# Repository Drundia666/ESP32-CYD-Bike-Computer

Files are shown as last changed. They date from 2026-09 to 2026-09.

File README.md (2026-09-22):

# ESP32-CYD-Bike-Computer
Open-source ESP32-CYD-based (Cheap Yellow Display) bicycle computer with a graphical display, speed tracking, trip statistics, environmental sensors, and customizable UI

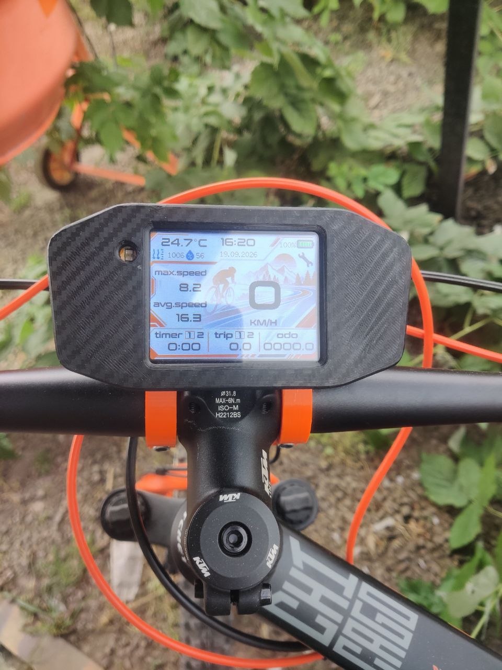
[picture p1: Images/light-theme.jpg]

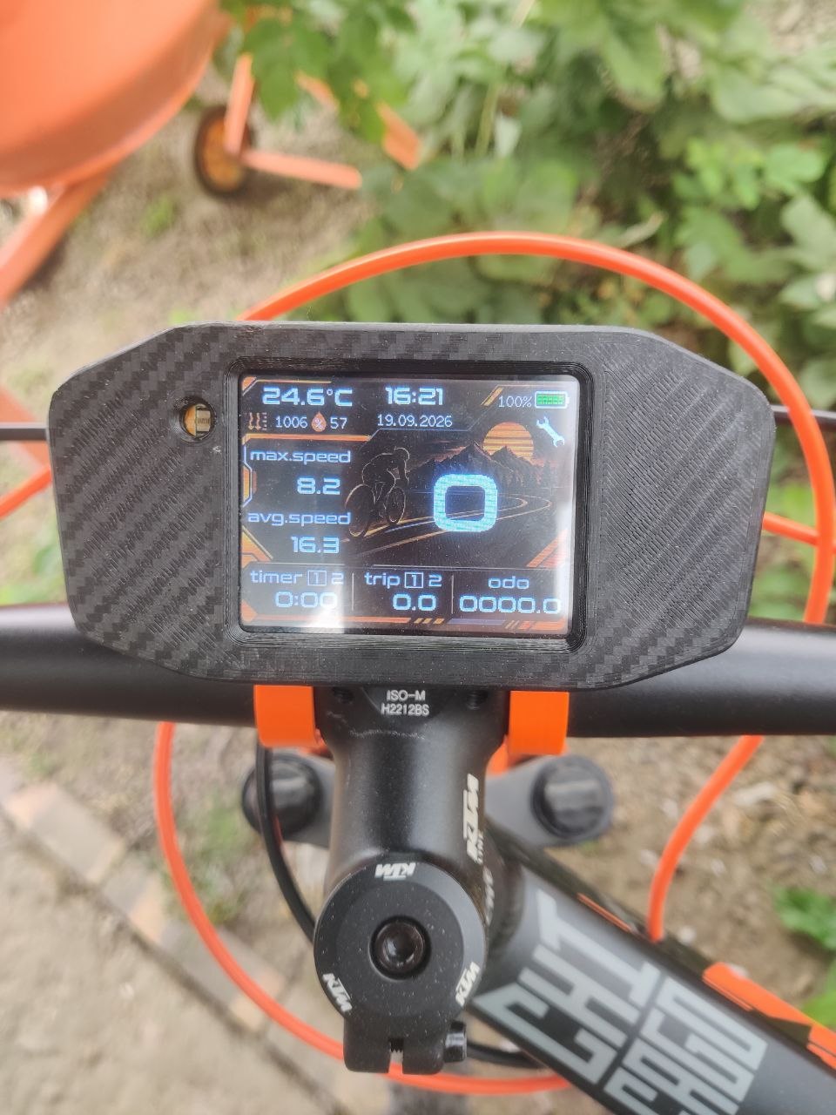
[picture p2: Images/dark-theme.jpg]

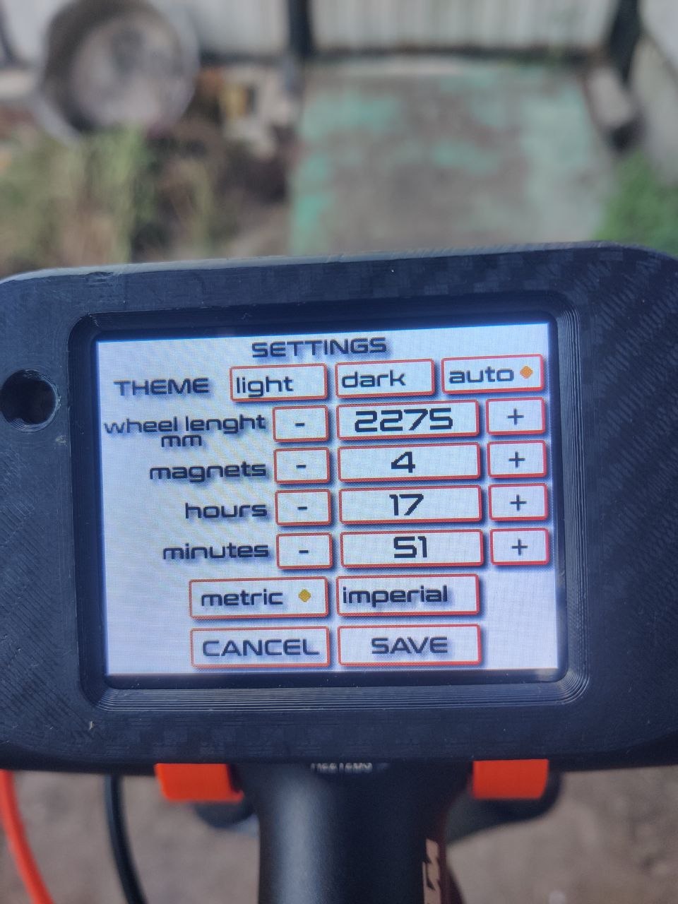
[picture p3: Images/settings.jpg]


## Features

- Real-time speed measurement
- Average and maximum speed
- Trip distance and total odometer
- Temperature, atmospheric pressure and humidity monitoring
- Trip timer

- Important Notice

This bike computer is a DIY hobby project intended for recreational use only.

It is not a professional-grade device.
Do not use it in competitions or situations where accurate measurements are critical.
It is not waterproof. Using it in rainy conditions is not recommended.

- # About the Project (для описания на русском листайте ниже)

The entire codebase was written by AI. It went through many iterations before I achieved the desired result, so the code may not be fully optimized.
This bike computer is installed on my personal KTM bicycle. That's also where the enclosure design comes from — it is inspired by the instrument cluster of the KTM Duke 790–890 motorcycles.
The mounting system should also fit bicycles from other brands with the following dimensions:

* Fork tube diameter: 35 mm
* Handlebar diameter at the mounting point: 32 mm
For other dimensions, you may need to make minor modifications to the 3D models of the mounting brackets.

---

## Assembly
Assembly is straightforward, but it requires basic soldering skills and some understanding of electrical circuits.

**The most important rule: always connect positive (+) to positive (+) and negative (−) to negative (−).**

If you don't understand the difference between positive and negative polarity, ask someone with electrical experience for help.

An assembly diagram is available in the `assembly photos` folder.

**Disclaimer:** I am not responsible for any damage caused by incorrect wiring or reversed polarity, including damage to microchips or other electronic components.

---

## Basic Operation

Using the bike computer is simple — turn it on and ride!

To turn it off, press and hold the button for 10 seconds.

### Timer

* Tap the **Timer** area to switch between active timers.
* Long-press the Timer area to reset the currently selected timer.

### Trip

* Tap the **Trip** area to switch between Trip 1 and Trip 2.
* Long-press the Trip area to reset the selected trip. This also resets the maximum and average speed recorded for that trip.

The total odometer runs continuously and saves its value to non-volatile memory every 100 meters.

### Battery Indicator

Tap the battery level indicator to switch between percentage (%) and voltage (V).

---

## Settings

Tap the wrench icon to open the Settings page.

### 1. Display Theme

Choose between three display modes:

* Light theme
* Dark theme
* Automatic switching based on the ambient light sensor

### 2. Wheel Circumference

The default wheel circumference is **2275 mm**, with an adjustment step of **5 mm**.

Alternatively, you can set the exact value directly in the source code.

Find the following line:

```cpp
float wheelCircumferenceMm = 2275;
```

Replace `2275` with your measured wheel circumference in millimeters.

### 3. Number of Wheel Magnets

Set the number of magnets installed on the wheel.

Using more magnets provides smoother speed measurements.

**Important:** If you use more than one magnet, they must be evenly spaced around the wheel, with an equal number of spokes between them.

### 4. Set Hours

Adjust the current hour.

### 5. Set Minutes

Adjust the current minute.

**Important:** The date is set automatically when the firmware is compiled. Therefore, the firmware must be compiled and uploaded on the same day to ensure the correct date.

### 6. Measurement Units

Choose between two measurement systems:

| Metric | Imperial |
| --- | --- |
| km | mi |
| km/h | mph |
| °C | °F |
| mmHg | inHg |

---

## How to Accurately Measure Wheel Circumference

Accurate wheel circumference measurement is important for correct speed and distance calculations.

Follow these steps:

1. Place your bicycle on a flat surface and position the wheel so that the tire valve is at the bottom, closest to the ground.
2. Make a mark on the ground directly below the valve.
3. Roll the bicycle forward until the wheel completes exactly one full revolution and the valve returns to the bottom.
4. Make a second mark on the ground.
5. Use a measuring tape to measure the distance between the two marks.

The measured distance is your wheel circumference in millimeters.

Enter this value in the bike computer settings or directly in the source code.

Troubleshooting
Speed Always Shows 0

If the speed reading remains at 0 km/h while riding, check the following:

Magnet is too far from the Hall sensor. The distance between the magnet and the sensor may be too large for reliable detection.
Magnet is not properly aligned. The magnet may be passing above or below the Hall sensor instead of directly in front of it.

Incorrect magnet polarity or Hall sensor orientation. The magnet may be facing the sensor with the wrong magnetic pole, or the Hall sensor may be installed facing the wrong direction.

Refer to the photos in the assembly photos folder for the correct Hall sensor orientation.

**Securing Components**

The magnetic USB connector, BME280 sensor, and 3-pin connector can be secured in place using a couple of drops of superglue.

It is recommended to secure the battery using hot glue. Additionally, place a thin layer of soft, electrically insulating material between the battery and the rear cover to provide cushioning and prevent direct contact.

## 🧡 Support the project

If you enjoy this project, you can support its development on Ko-fi.



# 🚴 Велокомпьютер на ESP32

Самодельный велокомпьютер на базе ESP32 с сенсорным управлением, измерением скорости и расстояния, двумя независимыми поездками, таймерами и возможностью настройки интерфейса.

Проект создан для личного использования и любительских экспериментов.

---

## ⚠️ Важная информация

> **Внимание!**
>
> * Устройство не является профессиональным измерительным прибором.
> * Не используйте его в соревнованиях.
> * Проект создан исключительно для любительского использования и развлечения.
> * Устройство не является водонепроницаемым. Использование во время дождя не рекомендуется.

---

## 📖 О проекте

Весь программный код написан с помощью ИИ (большая часть ChatGPT, также использован Claude и Github Copilot).

Проект прошёл множество итераций и доработок, прежде чем мне удалось получить желаемый результат. Поэтому код может быть не самым оптимальным, но он реализует необходимую мне функциональность.

Велокомпьютер установлен на моём личном велосипеде **KTM**. Именно поэтому корпус устройства стилизован под приборную панель мотоциклов KTM Duke 790–890.

### 🔧 Совместимость крепления

Крепление разработано под следующие размеры:

| Параметр | Размер |
| --- | --- |
| Диаметр пера вилки | 35 мм  |
| Диаметр руля в месте крепления | 32 мм  |

Устройство может подойти и для велосипедов других производителей с аналогичными размерами.

Если размеры вашего велосипеда отличаются, возможно, потребуется немного доработать 3D-модели крепёжных элементов.

---

## 🛠️ Сборка

Сборка достаточно простая, однако потребуются базовые навыки пайки и понимание основ электротехники.

### ⚡ Важно соблюдать полярность!

**Главное правило:**

* Плюс (+) соединяется с плюсом (+).
* Минус (−) соединяется с минусом (−).

Если вы не понимаете разницу между плюсом и минусом, обратитесь за помощью к человеку, имеющему опыт работы с электроникой.

📁 Схема сборки и фотографии правильного расположения компонентов находятся в папке `assembly photos`.

> ⚠️ **Отказ от ответственности**
>
> Автор не несёт ответственности за повреждение микросхем, датчиков и других электронных компонентов вследствие неправильного подключения, перепутанной полярности или ошибок при сборке.

---

## 🎮 Управление велокомпьютером

Управление максимально простое: включили устройство — и можно ехать!

### 🔘 Включение и выключение

| Действие | Результат |
| --- | --- |
| Включение устройства | Включите велокомпьютер и начинайте поездку |
| Удержание кнопки 10 секунд | Выключение устройства |

### ⏱️ Таймер — TIMER

Управление осуществляется касанием области `TIMER` на экране.

| Действие | Результат |
| --- | --- |
| Короткое касание | Переключение активного таймера |
| Долгое касание | Обнуление выбранного таймера |

### 🚴 Поездки — TRIP

Велокомпьютер поддерживает два независимых счётчика поездок: `TRIP 1` и `TRIP 2`.

| Действие | Результат |
| --- | --- |
| Короткое касание | Переключение между поездками 1 и 2 |
| Долгое касание | Сброс выбранной поездки |

При сбросе поездки также обнуляются:

* Максимальная скорость данной поездки.
* Средняя скорость данной поездки.

### 🛣️ Общий пробег — ODO

Общий одометр работает постоянно, независимо от выбранной поездки.

**Каждые 100 метров** значение общего пробега сохраняется в энергонезависимую память.

Это позволяет сохранять накопленный пробег после выключения устройства.

### 🔋 Индикатор батареи

Касание области индикатора заряда батареи переключает формат отображения:

* `%` — уровень заряда в процентах.
* `V` — напряжение аккумулятора в вольтах.

---

## ⚙️ Настройки

Чтобы открыть страницу настроек, коснитесь значка гаечного ключа 🔧 на экране.

В меню доступны следующие параметры.

### 1. 🎨 Тема оформления

Доступны три режима:

| Режим | Описание |
| --- | --- |
| Светлая тема | Светлое оформление интерфейса |
| Тёмная тема | Тёмное оформление интерфейса |
| Автоматический | Переключение темы по показаниям датчика освещённости |

### 2. 📏 Длина окружности колеса

Этот параметр необходим для правильного расчёта скорости и пройденного расстояния.

| Параметр | Значение |
| --- | --- |
| Значение по умолчанию | 2275 мм  |
| Шаг изменения | 5 мм |

Длину окружности можно изменить непосредственно в настройках велокомпьютера.

Также можно заранее указать необходимое значение в исходном коде.

Найдите строку:

```cpp
float wheelCircumferenceMm = 2275;
```

Замените `2275` на измеренную длину окружности вашего колеса в миллиметрах.

Подробная инструкция по измерению приведена ниже.

### 3. 🧲 Количество магнитов

Укажите количество магнитов, установленных на колесе.

Чем больше магнитов используется, тем плавнее происходит измерение скорости.

> ⚠️ **Важное правило**
>
> Если установлено более одного магнита, они должны располагаться равномерно по окружности колеса — через одинаковое количество спиц.

### 4. 🕒 Установка часов

Позволяет установить текущее значение часов.

### 5. 🕒 Установка минут

Позволяет установить текущее значение минут.

**Особенность установки даты:**

Дата устанавливается автоматически в момент компиляции прошивки.

Поэтому компиляция и загрузка прошивки в ESP32 должны выполняться в один и тот же день, чтобы дата была правильной.

### 6. 🌍 Система единиц измерения

Велокомпьютер поддерживает две системы единиц измерения.

| Параметр | Метрическая | Имперская |
| --- | :---: | :---: |
| Расстояние  | km | mi |
| Скорость | km/h | mph |
| Температура | °C | °F |
| Давление | mmHg | inHg |

---

## 📐 Как правильно измерить длину окружности колеса

Для точного измерения скорости и расстояния необходимо правильно указать длину окружности колеса.

Самый простой способ — измерить расстояние, которое велосипед проходит за один полный оборот колеса.

### Пошаговая инструкция

**Шаг 1. Подготовка**

Поставьте велосипед на ровную поверхность.

Поверните колесо так, чтобы ниппель находился в самой нижней точке, рядом с землёй.

**Шаг 2. Первая отметка**

Сделайте отметку на земле непосредственно под ниппелем.

**Шаг 3. Один оборот**

Прокатите велосипед вперёд ровно на один полный оборот колеса.

Остановитесь, когда ниппель снова окажется в нижней точке.

**Шаг 4. Вторая отметка**

Сделайте вторую отметку на земле.

**Шаг 5. Измерение**

С помощью обычной рулетки измерьте расстояние между двумя отметками.

Полученное значение в миллиметрах и есть длина окружности вашего колеса.

> 💡 **Совет**
>
> Для более точного результата измеряйте колесо при обычном давлении в шине и с привычной нагрузкой на велосипед.

Введите полученное значение в настройках велокомпьютера или непосредственно в исходном коде.

**Крепеж элементов**

Магнитный разъем, датчик BME280 и разъем 3-пин - крепятся с помощью пару капель суперклея
Аккумулятор лучше зафиксировать с помощью термоклея, а также между аккумулятором и задней крышкой желательно положить небольшой толщины мягкий изоляционный материал 

---

## 🔍 Возможные проблемы и их решение

### ❌ Скорость постоянно показывает 0

Если во время движения скорость остаётся равной нулю, проверьте следующие моменты.

**1. Слишком большое расстояние между магнитом и датчиком Холла**

Магнит может проходить слишком далеко от датчика, из-за чего тот не регистрирует его прохождение.

Решение: уменьшите расстояние между магнитом и датчиком.

**2. Неправильное положение магнита**

Магнит может проходить выше или ниже чувствительной области датчика Холла.

Решение: отрегулируйте положение магнита так, чтобы он проходил непосредственно напротив датчика.

**3. Неправильная полярность магнита или ориентация датчика Холла**

Возможные причины:

* Магнит обращён к датчику неподходящим магнитным полюсом.
* Датчик Холла установлен неправильной стороной к магниту.

Решение: проверьте ориентацию магнита и датчика Холла.

📁 Фотография правильного расположения датчика Холла находится в папке `assembly photos`.

---

## ❤️ Заключение

Это любительский DIY-проект, созданный для собственного велосипеда и удовольствия от процесса разработки.

Код может быть неидеальным, а конструкция — требовать адаптации под конкретный велосипед.

Надеюсь, проект окажется полезным тем, кто захочет собрать собственный велокомпьютер или использовать отдельные идеи в своих разработках.

**Приятной сборки и хороших поездок! 🚴**

## 🧡 Support the project

If you enjoy this project, you can support its development on Ko-fi.



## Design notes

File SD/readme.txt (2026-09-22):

Place these files in the root of the SD card.
положите эти файлы в корень SD карты

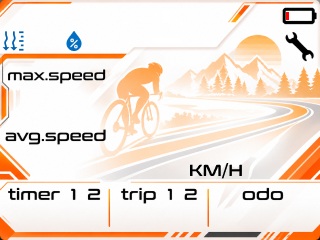
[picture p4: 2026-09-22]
SD/light.jpg

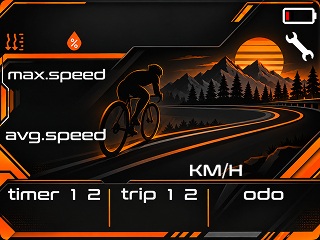
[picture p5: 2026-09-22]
SD/dark.jpg

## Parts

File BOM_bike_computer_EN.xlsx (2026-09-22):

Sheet: BOM
No. | Category | Reference | Component | Specifications | Qty (pcs) | Product link | Notes
1 | Electronics | MOD1 | ESP32 CYD JC2432W328 display module | 2.8 inch; ST7789; CAPACITIVE TOUCH ONLY | 1 | https://www.aliexpress.com/item/1005009206348081.html | Verify selected variant and module contents
2 | Electronics | MOD2 | TENSTAR BME280 3.3V | Temperature, humidity, pressure; I2C/SPI | 1 | https://www.aliexpress.com/item/1005009897980645.html | Verify supply voltage for the exact module
3 | Electronics | MOD3 | DS3231 + AT24C32 RTC module | I2C; real-time clock + EEPROM | 1 | https://www.aliexpress.com/item/1005006441905081.html | 3PCS refers to the seller pack, not the quantity per device
4 | Connectors | J1 | USB Type-C male plug | Male plug; exact configuration to be confirmed | 1 | https://www.aliexpress.com/item/1005004807492800.html | Do not substitute a female connector
5 | Connectors | J2 | Magnetic Pogo Pin Female STR | 4 pin; 2.54 mm according to listing title | 1 | https://www.aliexpress.com/item/1005009462593959.html | Verify selected variant, pinout and mating connector
6 | Hardware | H1–H2 | Heat-set threaded insert | M5 × L5 × OD7 | 2 |  | Material not confirmed
7 | Hardware | H3–H4 | M5 screw | M5 × 8 mm | 2 |  | CRITICAL: do not exceed 8 mm length. Longer screws may damage the Li-Po battery. Verify clearance.
8 | Hardware | H5–H12 | Countersunk screw | M3 × 6 mm | 8 |  | Drive type and material to be confirmed
9 | Hardware | H5–H12 | Countersunk screw | M3 × 10 mm | 1-4 |  | for fastening magnets
10 | Cables | W1 | JST MX1.25 cable | 2 pin; 10 cm; 28 AWG according to listing | 1 | https://www.aliexpress.com/item/1005007277110532.html | Verify actual connector type
11 | Cables | W2–W3 | JST MX1.25 cable | 4 pin; 10 cm; 28 AWG according to listing | 2 | https://www.aliexpress.com/item/1005007277110532.html | Verify actual connector type
12 | Connectors | J3 | JST XH-2.54 male | 3 pin | 1 |  | Verify compatibility with mating connector
13 | Connectors | J4 | JST XH-2.54 female — bent pin socket | 3 pin | 1 |  | Verify compatibility with mating connector
14 | Cables | W4 | Three-conductor cable | 3 conductors; an old USB cable may be reused |  |  | Length and quantity to be confirmed; inspect insulation and conductor gauge
15 | Hardware | H15–H16 | M5 self-locking nut | Polymer insert; | 2 |  | Confirm insert material; common locknuts often use nylon
16 | Hardware | H13–H14 | Countersunk screw | M5 × 35 mm | 2 |  | DO NOT use in place of M5×8 near battery; intended location to be confirmed
17 | Hardware |  | Round Magnet with holes | 10X3-3mm | 1-4 | https://www.aliexpress.com/item/1005010259347516.html | best result with 4pcs
18 | Hardware |  | LiPo 4000 mAh, 3,7В, 8x50x80мм LiPower LP805080 |  | 1 |  | with protection board. or choose ones of similar size

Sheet: Примечания
Parameter | Status
Number of BOM line items | 15
Quantities not provided | Items 1–5 and 13
Li-Po battery | Power source specified, but model and quantity not provided; not added as a purchasing line item
Critical safety restriction | Do not replace M5×8 screws with M5×35 near battery; verify mechanical clearance

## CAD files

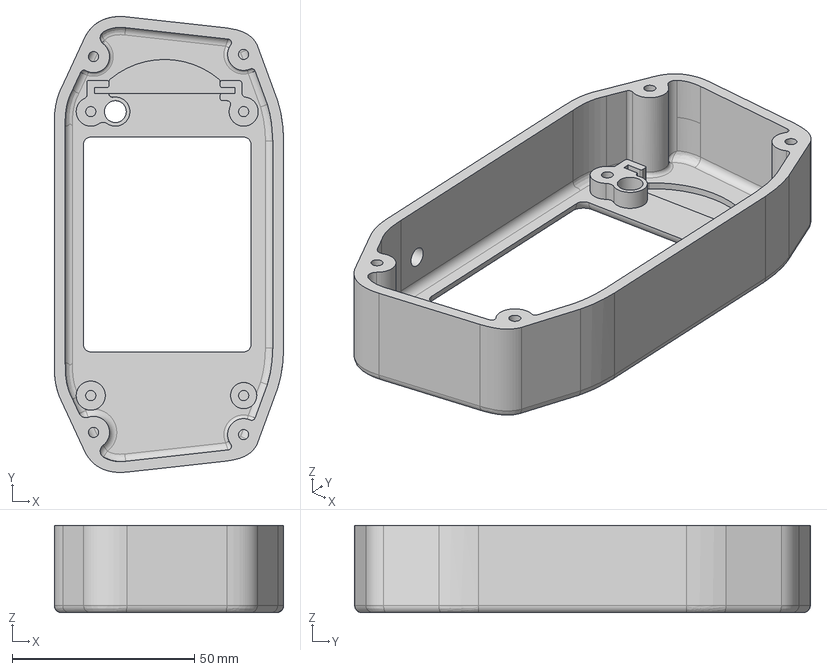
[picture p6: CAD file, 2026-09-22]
3d/Step/Main body.step
63.0 x 125.3 x 24.0 mm

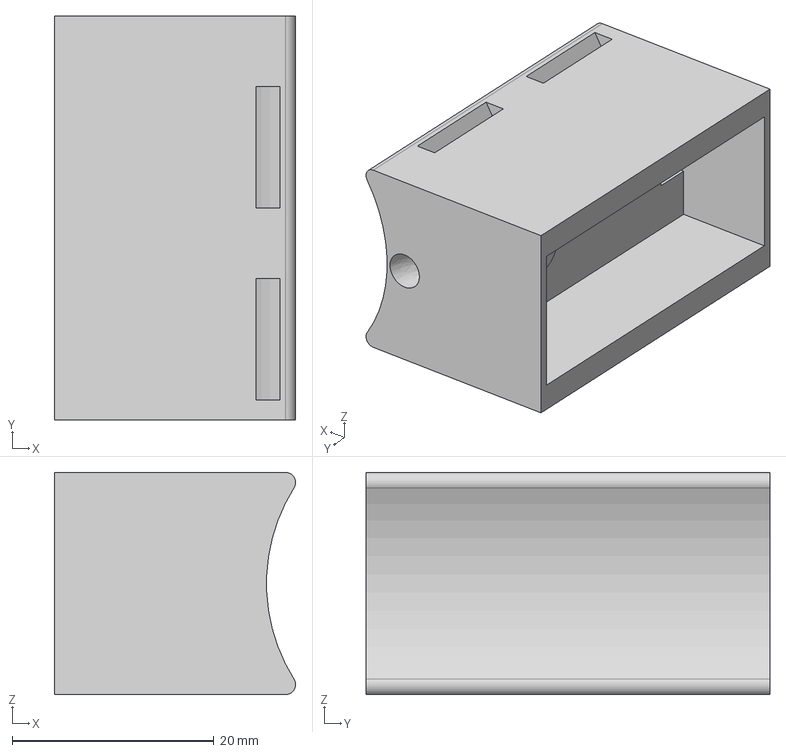
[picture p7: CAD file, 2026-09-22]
3d/Step/ky-024 holder.step
23.9 x 40.0 x 22.0 mm

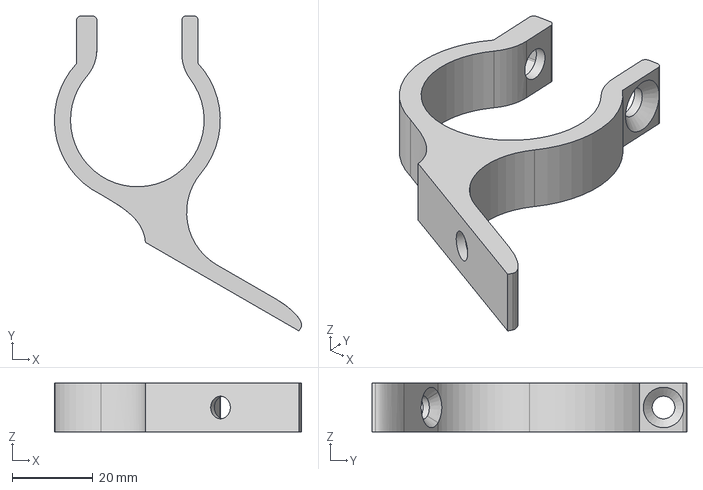
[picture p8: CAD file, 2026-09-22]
3d/Step/handlebar mount.step
61.1 x 77.8 x 12.0 mm

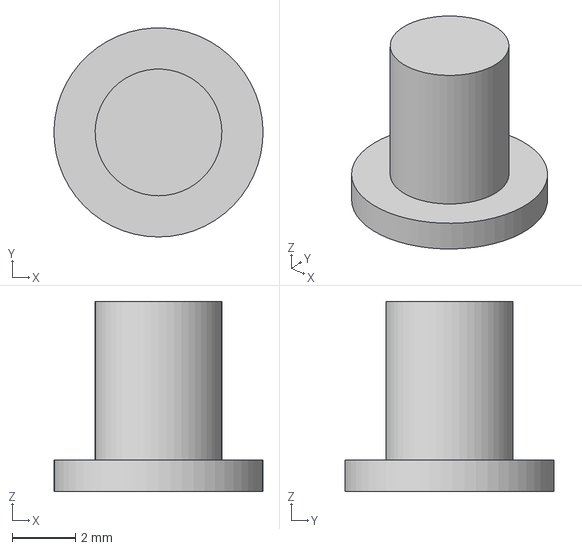
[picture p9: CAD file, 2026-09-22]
3d/Step/button.step
6.60 x 6.59 x 6.00 mm

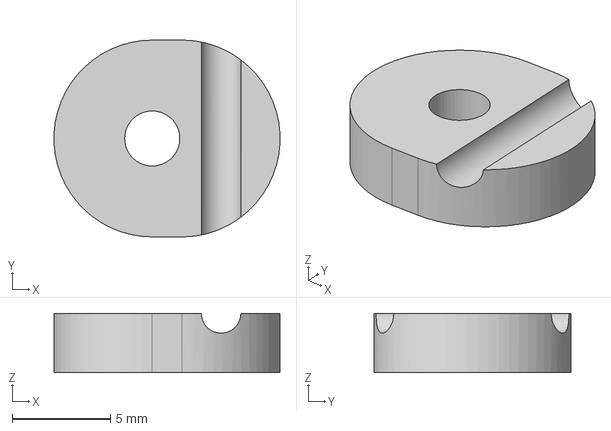
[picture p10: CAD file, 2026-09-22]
3d/Step/magnet holder2.step
11.5 x 10.0 x 3.00 mm

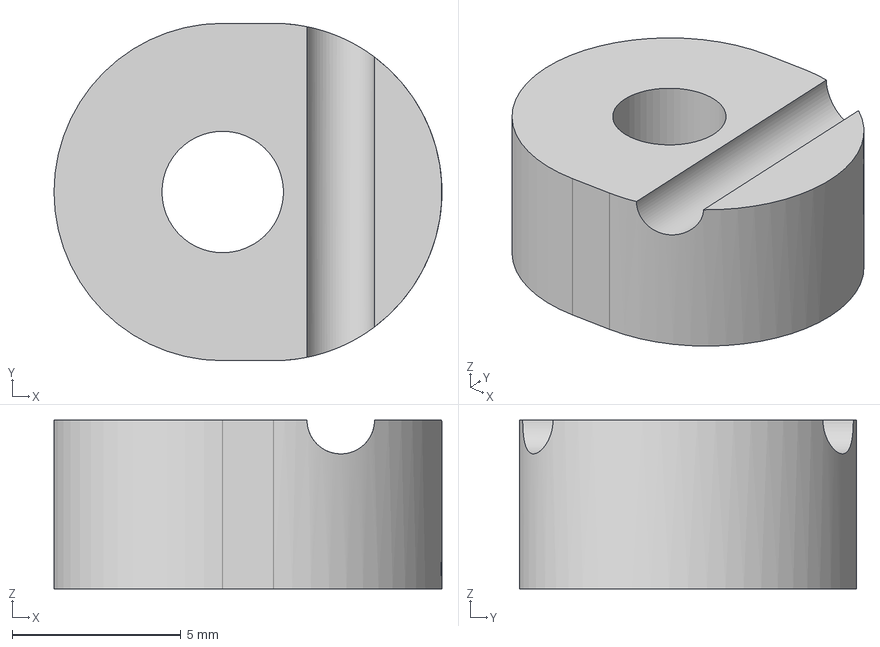
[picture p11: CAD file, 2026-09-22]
3d/Step/magnet holder1.step
11.5 x 10.0 x 5.00 mm

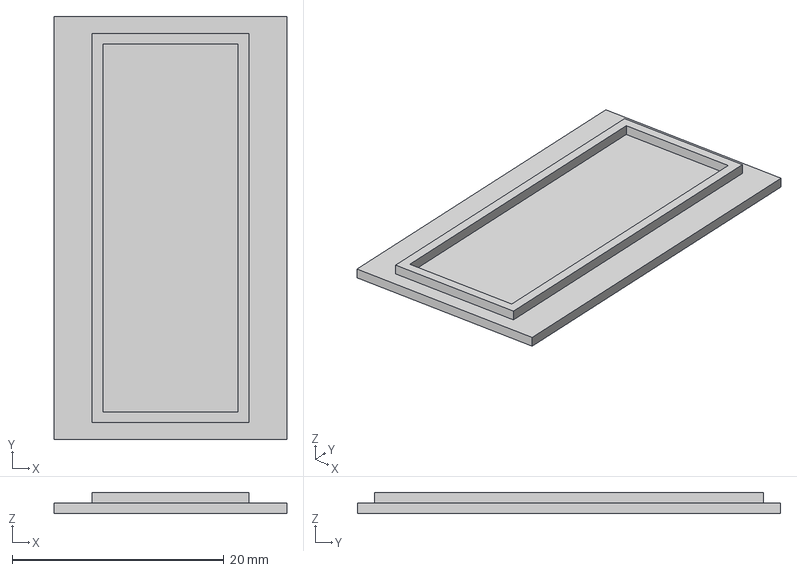
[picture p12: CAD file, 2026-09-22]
3d/Step/ky-024 cap.step
22.0 x 40.0 x 2.00 mm

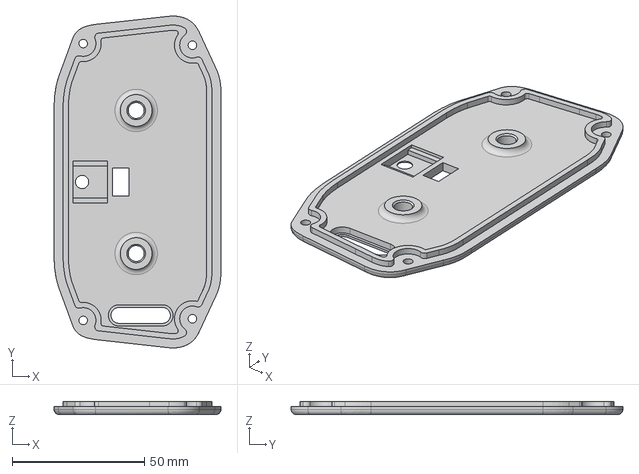
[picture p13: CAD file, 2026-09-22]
3d/Step/back cover.step
63.0 x 125.3 x 5.00 mm

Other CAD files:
3d/STL/back cover.stl
3d/STL/button.stl
3d/STL/handlebar mount.stl
3d/STL/ky-024 cap.stl
3d/STL/ky-024 holder.stl
3d/STL/magnet holder1.stl
3d/STL/magnet holder2.stl
3d/STL/main body.stl

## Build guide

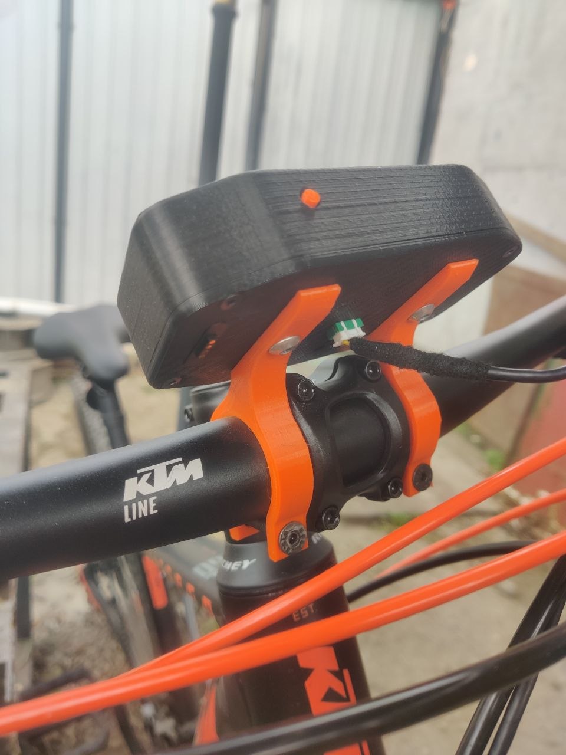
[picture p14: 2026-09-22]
Assembly photos/photo_2026-09-22_13-49-20.jpg

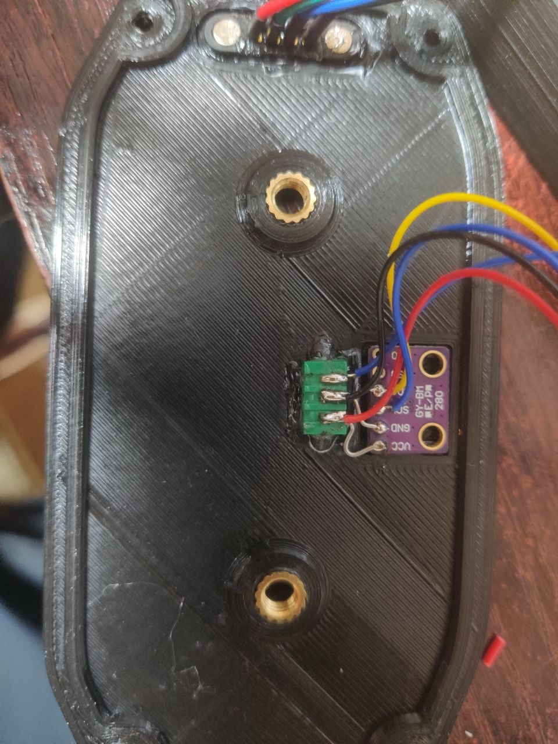
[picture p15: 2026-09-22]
Assembly photos/photo_2026-09-20_20-18-47.jpg

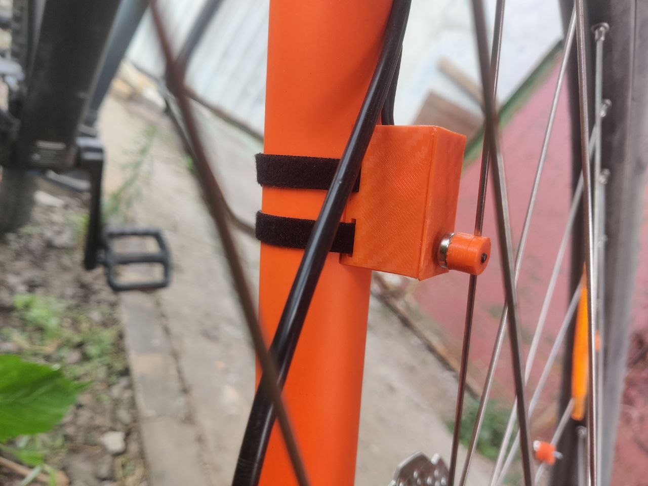
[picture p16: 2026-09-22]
Assembly photos/photo_2026-09-22_13-49-23.jpg

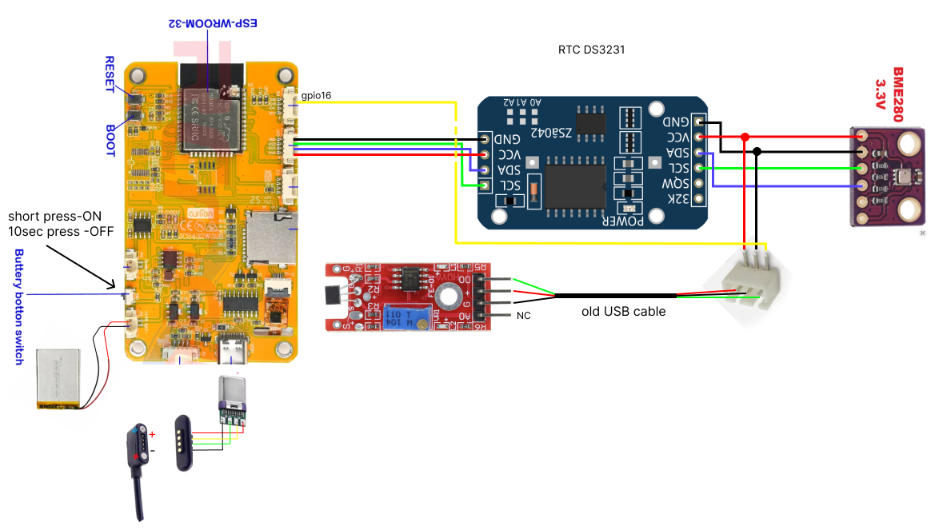
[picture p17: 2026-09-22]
Assembly photos/Scheme.jpg

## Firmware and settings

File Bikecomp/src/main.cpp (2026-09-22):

#include <Arduino.h>
#include <cstring>

//#include <bb_captouch.h>

/*
  ============================================================
  ВЕЛОКОМПЬЮТЕР ESP32 (JC2432W328 / ST7789) — V4
  ============================================================

  Датчики / модули:
    KY-024 Hall       -> GPIO16
    BME280 (t/давл/влажн) -> I2C шина Wire: SDA=GPIO21, SCL=GPIO22
    DS3231 (RTC)      -> та же I2C шина Wire (SDA=GPIO21, SCL=GPIO22)
    CST820 (тач)      -> ОТДЕЛЬНАЯ I2C шина touchWire: SDA=GPIO33, SCL=GPIO32
    Батарея           -> GPIO39   (аналог, через делитель напряжения)
    Фоторезистор (LDR)-> GPIO34   (аналог)

    ПРОВЕРЬТЕ все пины на вашей плате! DS18B20 в текущем коде не
    используется — температура/давление/влажность берутся с BME280.

  Экран:
    320x240, Rotation 1
    Тема: белый фон / чёрный текст (день) <-> чёрный фон / белый текст (ночь)
    Оранжевые акценты — НЕ зависят от темы, остаются оранжевыми всегда

  РАСКЛАДКА:

    Верхняя строка:
      [температура]      [часы:минуты]      [батарея]

    Скорость:
      крупно по центру

    Если тема переключается "наоборот" (темнеет на свету) —
      поменяйте местами сравнения в updateAmbientLight() или
      просто инвертируйте LIGHT_THRESHOLD_DARK / LIGHT_THRESHOLD_LIGHT
      логику (< на >). Направление зависит от того, как включён
      делитель (LDR сверху к VCC или снизу к GND).
*/


#include <TFT_eSPI.h>
#include <Adafruit_BME280.h>
#include <Preferences.h>
#include <Wire.h>
#include <RTClib.h>
#include <CST820.h>
#include <SD.h>
#include <SPI.h>
#include <TJpg_Decoder.h>
#include <FS.h>


// ============================================================
// ОБЪЕКТЫ
// ============================================================

TFT_eSPI tft = TFT_eSPI();
TFT_eSprite speedSprite = TFT_eSprite(&tft);
Preferences prefs;
Adafruit_BME280 bme;

RTC_DS3231 rtc;
bool rtcAvailable = false;
bool bmeAvailable = false;
TwoWire touchWire = TwoWire(1);
int clockSetHour = 0;
int clockSetMinute = 0;
bool clockTimeChanged = false;


// ============================================================
// НАСТРОЙКИ / ПИНЫ
// ============================================================

const int HALL_PIN       = 16;
const int BACKLIGHT_PIN  = 27;   // TFT_BL на JC2432W328
const int BATTERY_PIN    = 39;   // input-only ADC, обычно свободен
const int LDR_PIN        = 34;   // фоторезистор, input-only ADC
const uint8_t BME280_ADDR = 0x76;

const int SD_CS_PIN = 5;   // ПРОВЕРЬТЕ пин CS для вашей ревизии JC2432W328!
const char* BOOT_IMAGE_PATH = "/logo.jpg";
const char* LIGHT_BACKGROUND_PATH = "/light.jpg";
const char* DARK_BACKGROUND_PATH = "/dark.jpg";
const char* LIGHT_MPH_BACKGROUND_PATH = "/lightmph.jpg";
const char* DARK_MPH_BACKGROUND_PATH = "/darkmph.jpg";
const char* SETTINGS_BACKGROUND_PATH = "/settings.jpg";
bool sdAvailable = false;

// Основная I2C шина для BME280 и DS3231.
const int I2C_SDA_PIN = 21;
const int I2C_SCL_PIN = 22;

// Отдельная I2C шина для CST820.
const int TOUCH_SDA_PIN = 33;
const int TOUCH_SCL_PIN = 32;

// CST820 — встроенный ёмкостный тач JC2432W328
const uint8_t TOUCH_I2C_ADDR = 0x15;
const int TOUCH_RST_PIN = 25;

// Длина окружности колеса (мм)
float wheelCircumferenceMm = 2275.0;
// Сколько магнитов установлено на колесе (равномерно по окружности).
// Меняет ТОЛЬКО частоту срабатывания датчика — settings и NVS
// по-прежнему хранят полную окружность колеса в мм.
int magnetsPerRevolution = 1;
const int MAGNETS_MIN = 1;
const int MAGNETS_MAX = 4;

// Шаг изменения окружности колеса в настройках
const float CIRCUMFERENCE_STEP_MM = 5.0;
const float CIRCUMFERENCE_MIN_MM  = 1000.0;
const float CIRCUMFERENCE_MAX_MM  = 3000.0;

// Антидребезг Hall
const unsigned long DEBOUNCE_US = 15000;

// Фильтр ложных импульсов Hall.
// Импульс полностью отбрасывается ДО увеличения pulseCount, если он
// соответствует физически неправдоподобной скорости или слишком резкому
// одиночному скачку относительно предыдущего принятого импульса.
const float MAX_PLAUSIBLE_SPEED_KMH = 65.0f;
const float MAX_SPEED_JUMP_KMH      = 15.0f;

// Скорость = 0, если импульсов нет дольше этого времени
const unsigned long SPEED_TIMEOUT_MS = 2000;

// Интервал обновления температуры
const unsigned long TEMP_UPDATE_MS = 5000;

// Интервал обновления батареи
const unsigned long BATTERY_UPDATE_MS = 5000;

// Сколько сэмплов усредняем при чтении батареи
const int BATTERY_SAMPLES = 16;

// Делитель напряжения: Vbat = Vadc * BATTERY_DIVIDER_RATIO
// Подберите под свои резисторы!
const float BATTERY_DIVIDER_RATIO = 1.61;

// Диапазон напряжения LiPo для расчёта процента
const float BATTERY_MIN_V = 3.3;
const float BATTERY_MAX_V = 4.2;


// Сохранять общий пробег каждые 0.1 км
const float ODOMETER_SAVE_STEP_KM = 0.1;

// Заставка
const unsigned long BOOT_LOGO_MS = 3000;

// -------------------- Фоторезистор / тема --------------------
const unsigned long LIGHT_UPDATE_MS = 2000;
const int LIGHT_SAMPLES = 16;

// Пороги с гистерезисом (сырые значения ADC, 0..4095).
// У вашей схемы: на свету ADC ~0, в темноте (закрыт) ~1770.
// Значит чем темнее, тем БОЛЬШЕ значение ADC.
const int LIGHT_THRESHOLD_DARK  = 100;   // выше -> переключаемся в тёмную тему
const int LIGHT_THRESHOLD_LIGHT = 30;   // ниже -> переключаемся в светлую тему


// ============================================================
// ЦВЕТА
// ============================================================

// Фон и текст — теперь переменные, т.к. меняются по освещённости.
uint16_t colBg   = TFT_WHITE;
uint16_t colText = TFT_BLACK;

// ============================================================
// HALL (без изменений по логике)
// ============================================================

volatile unsigned long pulseCount = 0;
volatile unsigned long lastPulseMicros = 0;
volatile unsigned long pulseIntervalMicros = 0;
// Минимальный допустимый интервал между настоящими импульсами Hall.
// Значение рассчитывается ВНЕ ISR, чтобы внутри прерывания не было float/FPU.
volatile unsigned long hallMinIntervalUs = DEBOUNCE_US;
unsigned long hallAbsoluteMinIntervalUs = DEBOUNCE_US;
// Суммарное время фактического движения. В него попадают только
// интервалы между последовательными импульсами колеса короче таймаута.
volatile uint64_t totalMovingMicros = 0;

// Пересчитать абсолютный предел Hall по длине колеса, количеству магнитов
// и MAX_PLAUSIBLE_SPEED_KMH. Вызывать только из обычного кода, НЕ из ISR.
void updateHallAbsoluteFilterLimit()
{
  float distancePerPulseMm = wheelCircumferenceMm / magnetsPerRevolution;
  unsigned long limitUs = (unsigned long)(
      (distancePerPulseMm * 3600.0f) / MAX_PLAUSIBLE_SPEED_KMH);

  if (limitUs < DEBOUNCE_US)
    limitUs = DEBOUNCE_US;

  hallAbsoluteMinIntervalUs = limitUs;
  hallMinIntervalUs = limitUs;
}

void IRAM_ATTR onHallPulse()
{
  unsigned long now = micros();

  if (lastPulseMicros == 0)
  {
    lastPulseMicros = now;
    pulseCount++;
    return;
  }

  unsigned long delta = now - lastPulseMicros;

  // В ISR только быстрые целочисленные операции.
  // Никаких float, делений или FPU внутри аппаратного прерывания.
  if (delta < hallMinIntervalUs)
    return;

  pulseIntervalMicros = delta;

  if (delta <= (SPEED_TIMEOUT_MS * 1000UL))
    totalMovingMicros += delta;

  lastPulseMicros = now;
  pulseCount++;
}

// ============================================================
// JPEG DECODER CALLBACK
// ============================================================
// TJpg_Decoder вызывает эту функцию для каждого декодированного
// блока изображения и сам передаёт координаты/размер/пиксели.
bool tftOutput(int16_t x, int16_t y, uint16_t w, uint16_t h, uint16_t* bitmap)
{
  if (y >= tft.height()) return 0;

  tft.pushImage(x, y, w, h, bitmap);

  return 1; // продолжить декодирование
}

uint16_t* backgroundTemp = nullptr;
uint16_t* backgroundClock = nullptr;
uint16_t* backgroundBattery = nullptr;
uint16_t* backgroundMetrics = nullptr;
uint16_t* backgroundTimer = nullptr;
uint16_t* backgroundTrip = nullptr;
uint16_t* backgroundOdometer = nullptr;
uint16_t* backgroundSpeed = nullptr;
uint16_t* backgroundTimerLabel = nullptr;
uint16_t* backgroundTripLabel = nullptr;

// Маленькие буферы фона Settings: позволяют менять значения без
// повторной отрисовки всего /settings.jpg.
uint16_t* settingsWheelBg = nullptr;
uint16_t* settingsMagnetsBg = nullptr;
uint16_t* settingsHoursBg = nullptr;
uint16_t* settingsMinutesBg = nullptr;

// ============================================================
// USB / SERIAL -> SD SERVICE MODE
// ============================================================
// Компьютер посылает строку "SDUP" через USB-COM. После этого
// основной интерфейс останавливается, крупные графические буферы
// освобождаются, а файлы принимаются небольшими блоками и
// записываются прямо на SD-карту. Wi-Fi для этого не нужен.
bool sdUsbMode = false;
const size_t SD_USB_BLOCK_SIZE = 512;
const unsigned long SD_USB_RX_TIMEOUT_MS = 10000;
const char* SD_USB_TEMP_PATH = "/.__upload.tmp";

const int SETTINGS_WHEEL_BG_X = 176;
const int SETTINGS_WHEEL_BG_Y = 54;
const int SETTINGS_WHEEL_BG_W = 82;
const int SETTINGS_WHEEL_BG_H = 28;

const int SETTINGS_MAGNETS_BG_X = 186;
const int SETTINGS_MAGNETS_BG_Y = 84;
const int SETTINGS_MAGNETS_BG_W = 45;
const int SETTINGS_MAGNETS_BG_H = 26;

const int SETTINGS_HOURS_BG_X = 191;
const int SETTINGS_HOURS_BG_Y = 114;
const int SETTINGS_HOURS_BG_W = 42;
const int SETTINGS_HOURS_BG_H = 24;

const int SETTINGS_MINUTES_BG_X = 196;
const int SETTINGS_MINUTES_BG_Y = 144;
const int SETTINGS_MINUTES_BG_W = 43;
const int SETTINGS_MINUTES_BG_H = 24;

void copyBackgroundBlock(int16_t x, int16_t y, uint16_t w, uint16_t h,
                         uint16_t* bitmap, int regionX, int regionY,
                         int regionW, int regionH, uint16_t* destination)
{
  if (!destination || x >= regionX + regionW || x + w <= regionX ||
      y >= regionY + regionH || y + h <= regionY)
    return;

  int startX = max((int)x, regionX);
  int endX = min((int)x + (int)w, regionX + regionW);
  int startY = max((int)y, regionY);
  int endY = min((int)y + (int)h, regionY + regionH);

  for (int row = startY; row < endY; row++)
  {
    uint16_t* source = bitmap + (row - y) * w + (startX - x);
    uint16_t* target = destination + (row - regionY) * regionW + (startX - regionX);
    memcpy(target, source, (endX - startX) * sizeof(uint16_t));
  }
}

bool backgroundBufferOutput(int16_t x, int16_t y, uint16_t w, uint16_t h, uint16_t* bitmap)
{
  copyBackgroundBlock(x, y, w, h, bitmap, 0, 0, 120, 72, backgroundTemp);
  copyBackgroundBlock(x, y, w, h, bitmap, 112, 0, 100, 60, backgroundClock);
  // Y = 6 соответствует BATTERY_Y - 12 (см. restoreMainBackgroundRegion
  // и вызов в drawBatteryIcon) — раньше здесь было 8, из-за чего
  // буфер фона и место восстановления не совпадали на 2px.
  copyBackgroundBlock(x, y, w, h, bitmap, 240, 6, 75, 22, backgroundBattery);
  copyBackgroundBlock(x, y, w, h, bitmap, 0, 60, 118, 126, backgroundMetrics);
  copyBackgroundBlock(x, y, w, h, bitmap, 2, 202, 102, 32, backgroundTimer);
  copyBackgroundBlock(x, y, w, h, bitmap, 108, 202, 103, 32, backgroundTrip);
  copyBackgroundBlock(x, y, w, h, bitmap, 215, 202, 103, 32, backgroundOdometer);
  copyBackgroundBlock(x, y, w, h, bitmap, 138, 80, 165, 70, backgroundSpeed);
  copyBackgroundBlock(x, y, w, h, bitmap, 0, 177, 106, 28, backgroundTimerLabel);
  copyBackgroundBlock(x, y, w, h, bitmap, 108, 177, 103, 28, backgroundTripLabel);
  return 1;
}

bool settingsBackgroundBufferOutput(int16_t x, int16_t y, uint16_t w, uint16_t h, uint16_t* bitmap)
{
  copyBackgroundBlock(x, y, w, h, bitmap,
                      SETTINGS_WHEEL_BG_X, SETTINGS_WHEEL_BG_Y,
                      SETTINGS_WHEEL_BG_W, SETTINGS_WHEEL_BG_H, settingsWheelBg);

  copyBackgroundBlock(x, y, w, h, bitmap,
                      SETTINGS_MAGNETS_BG_X, SETTINGS_MAGNETS_BG_Y,
                      SETTINGS_MAGNETS_BG_W, SETTINGS_MAGNETS_BG_H, settingsMagnetsBg);

  copyBackgroundBlock(x, y, w, h, bitmap,
                      SETTINGS_HOURS_BG_X, SETTINGS_HOURS_BG_Y,
                      SETTINGS_HOURS_BG_W, SETTINGS_HOURS_BG_H, settingsHoursBg);

  copyBackgroundBlock(x, y, w, h, bitmap,
                      SETTINGS_MINUTES_BG_X, SETTINGS_MINUTES_BG_Y,
                      SETTINGS_MINUTES_BG_W, SETTINGS_MINUTES_BG_H, settingsMinutesBg);

  return 1;
}

// ============================================================
// СОСТОЯНИЕ
// ============================================================

float speedKmh = 0.0;
float trip1Km = 0.0;
float trip2Km = 0.0;
// avg.speed и max.speed считаются отдельно для trip1 и trip2,
// чтобы долгое нажатие (сброс trip) сбрасывало их вместе с пробегом.
float trip1MaxSpeedKmh = 0.0;
float trip2MaxSpeedKmh = 0.0;
// База накопленного времени движения для каждого trip.
uint64_t trip1MovingBaseMicros = 0;
uint64_t trip2MovingBaseMicros = 0;
float odometerKm = 0.0;
float odometerAtLastSave = 0.0;
unsigned long lastProcessedPulseCount = 0;

float currentTempC = NAN;
float currentPressurePa = 0.0f;
float currentHumidityPercent = 0.0f;
unsigned long lastTempRequest = 0;
enum SpeedUnit { SPEED_KMH = 0, SPEED_MPH = 1 };
enum TemperatureUnit { TEMP_CELSIUS = 0, TEMP_FAHRENHEIT = 1 };
enum PressureUnit { PRESSURE_HPA = 0, PRESSURE_MMHG = 1, PRESSURE_MBAR = 2, PRESSURE_INHG = 3 };

const float KMH_TO_MPH = 0.621371f;

SpeedUnit speedUnit = SPEED_KMH;
TemperatureUnit temperatureUnit = TEMP_CELSIUS;
PressureUnit pressureUnit = PRESSURE_HPA;

int batteryPercent = -1;
float batteryVoltageV = 0.0;
bool batteryShowVoltage = false;
unsigned long lastBatteryRead = 0;

enum ThemeMode {
  THEME_WHITE = 0,
  THEME_DARK  = 1,
  THEME_AUTO  = 2
};

ThemeMode themeMode = THEME_WHITE;
bool isDarkTheme = false;
unsigned long lastLightRead = 0;

bool settingsScreen = false;
bool touchWasDown = false;
unsigned long lastTouchMs = 0;
char lastDrawnAvgLabel[16] = "";
char lastDrawnMaxLabel[16] = "";
float lastDrawnAvgMetricValue = NAN;
float lastDrawnMaxMetricValue = NAN;

int activeTimerIndex = 0;
unsigned long timer1StartedAtMs = 0;
unsigned long timer2StartedAtMs = 0;
unsigned long timer1AccumulatedMs = 0;
unsigned long timer2AccumulatedMs = 0;
bool timerPressActive = false;
unsigned long timerPressStartMs = 0;
char lastDrawnTimerLabel[16] = "";
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
void loop()
{
  if (sdUsbMode)
  {
    sdUsbServiceLoop();
    delay(1);
    return;
  }

  checkForSdUsbRequest();
  if (sdUsbMode)
    return;

  unsigned long nowMs = millis();

  updateSpeedAndDistance();
  updateTemperature(nowMs);
  updateBattery(nowMs);
  updateAmbientLight(nowMs);
  maybeSaveOdometer();

  handleTouch();

  if (!settingsScreen)
  {
    drawTopRow();
    drawSpeed();
    drawBottomValues(nowMs);
  }
}


// ============================================================
// HALL — СКОРОСТЬ + ПРОБЕГ
// ============================================================

void updateSpeedAndDistance()
{
  unsigned long count;
  unsigned long lastPulse;
  unsigned long interval;

  noInterrupts();
  count = pulseCount;
  lastPulse = lastPulseMicros;
  interval = pulseIntervalMicros;
  interrupts();

  float distancePerPulseMm = wheelCircumferenceMm / magnetsPerRevolution;

  if (count != lastProcessedPulseCount)
  {
    unsigned long newPulses = count - lastProcessedPulseCount;
    float addedKm = (newPulses * distancePerPulseMm) / 1000000.0;

    trip1Km += addedKm;
    trip2Km += addedKm;

    odometerKm += addedKm;
    lastProcessedPulseCount = count;
  }

  if (lastPulse == 0)
  {
    speedKmh = 0.0;
    hallMinIntervalUs = hallAbsoluteMinIntervalUs;
    return;
  }

  unsigned long sinceLastPulseMs = (micros() - lastPulse) / 1000;

  if (sinceLastPulseMs > SPEED_TIMEOUT_MS)
  {
    speedKmh = 0.0;

    // Сбрасываем метку последнего импульса: иначе первый импульс
    // после долгой остановки посчитает интервал от импульса ДО
    // остановки и даст заниженную (почти нулевую) скорость на кадр.
    // Проверка lastPulseMicros == lastPulse защищает от гонки,
    // если импульс успел прийти между чтением выше и этим сбросом.
    noInterrupts();
    if (lastPulseMicros == lastPulse)
    {
      lastPulseMicros = 0;
      pulseIntervalMicros = 0;
      hallMinIntervalUs = hallAbsoluteMinIntervalUs;
    }
    interrupts();

    return;
  }

  if (interval == 0)
  {
    speedKmh = 0.0;
    return;
  }

  float intervalSec = interval / 1000000.0;
  float distancePerPulseM = distancePerPulseMm / 1000.0;
  float speedMs = distancePerPulseM / intervalSec;

  speedKmh = speedMs * 3.6;

  // Рассчитать порог для следующего импульса вне ISR.
  float allowedNextSpeedKmh = speedKmh + MAX_SPEED_JUMP_KMH;
  if (allowedNextSpeedKmh > MAX_PLAUSIBLE_SPEED_KMH)
    allowedNextSpeedKmh = MAX_PLAUSIBLE_SPEED_KMH;

  unsigned long dynamicMinIntervalUs = (unsigned long)(
      (distancePerPulseMm * 3600.0f) / allowedNextSpeedKmh);
  if (dynamicMinIntervalUs < hallAbsoluteMinIntervalUs)
    dynamicMinIntervalUs = hallAbsoluteMinIntervalUs;

  hallMinIntervalUs = dynamicMinIntervalUs;

  if (speedKmh > trip1MaxSpeedKmh)
    trip1MaxSpeedKmh = speedKmh;
  if (speedKmh > trip2MaxSpeedKmh)
    trip2MaxSpeedKmh = speedKmh;
}

// ============================================================
// ТЕМПЕРАТУРА (без изменений)
// ============================================================

void updateTemperature(unsigned long nowMs)
{
  if (nowMs - lastTempRequest < TEMP_UPDATE_MS && lastTempRequest != 0)
    return;

  lastTempRequest = nowMs;

  if (!bmeAvailable)
  {
    currentTempC = NAN;
    currentPressurePa = 0.0f;
    currentHumidityPercent = 0.0f;
    return;
  }

  currentTempC = bme.readTemperature();
  currentPressurePa = bme.readPressure();
  currentHumidityPercent = bme.readHumidity();

  if (isnan(currentTempC))
  {
    Serial.println("BME280 read failed");
  }
}


// ============================================================
// БАТАРЕЯ
// ============================================================

void updateBattery(unsigned long nowMs)
{
  if (nowMs - lastBatteryRead < BATTERY_UPDATE_MS && lastBatteryRead != 0)
  {
    return;
  }

  lastBatteryRead = nowMs;

  long sum = 0;

  for (int i = 0; i < BATTERY_SAMPLES; i++)
  {
    sum += analogRead(BATTERY_PIN);
    delay(2);
  }

  float raw = sum / (float)BATTERY_SAMPLES;
  float vAdc = (raw / 4095.0) * 3.3;
  float vBat = vAdc * BATTERY_DIVIDER_RATIO;
  batteryVoltageV = vBat;

  float pct = (vBat - BATTERY_MIN_V) / (BATTERY_MAX_V - BATTERY_MIN_V) * 100.0;

  if (pct < 0) pct = 0;
  if (pct > 100) pct = 100;

  batteryPercent = (int)(pct + 0.5);

  // Вывод значения GPIO39 в Serial Monitor
  Serial.print("GPIO39 raw: ");
  Serial.print(raw);
  Serial.print(" | Vadc: ");
  Serial.print(vAdc, 3);
  Serial.print(" V | Vbat: ");
  Serial.print(vBat, 3);
  Serial.print(" V | Battery: ");
  Serial.print(batteryPercent);
  Serial.println(" %");
}


// ============================================================
// ФОТОРЕЗИСТОР / АВТО-ТЕМА
// ============================================================

// Усреднённое сырое значение ADC с фоторезистора.
int readLightRaw()
{
  long sum = 0;

  for (int i = 0; i < LIGHT_SAMPLES; i++)
  {
    sum += analogRead(LDR_PIN);
  }

  return sum / LIGHT_SAMPLES;
}

// Разовое определение "темно сейчас или нет" — используется в setup(),
// без гистерезиса (гистерезис нужен только чтобы не мигало в loop()).
bool readIsDark()
{
  int raw = readLightRaw();
  return raw > LIGHT_THRESHOLD_DARK;
}

// Применяет цвета выбранной темы (не трогает экран, только переменные).
void applyThemeColors(bool dark)
{
  if (dark)
  {
    colBg   = TFT_BLACK;
    colText = TFT_WHITE;
  }
  else
  {
    colBg   = TFT_WHITE;
    colText = TFT_BLACK;
  }
}

// Сбрасывает все "последние отрисованные" значения, чтобы на
// следующем кадре все элементы перерисовались с новыми цветами.
void forceFullRedraw()
{
  lastDrawnSpeed = -1.0;
  lastDrawnAvgSpeed = -1.0;
  lastDrawnMaxSpeed = -1.0;
  lastDrawnTrip = -1.0;
  lastDrawnOdo = -1.0;
  lastDrawnTemp = -999.0;
  lastDrawnPressure = NAN;
  lastDrawnHumidity = NAN;
  lastDrawnBatteryPct = -999;
  lastDrawnClockH = -1;
  lastDrawnClockM = -1;
  lastDrawnDateDay = -1;
  lastDrawnDateMonth = -1;
  lastDrawnDateYear = -1;
  lastDrawnTimerTotalSec = -1;
  lastDrawnTimerLabel[0] = '\0';
  lastDrawnTripLabel[0] = '\0';
  lastDrawnAvgLabel[0] = '\0';
  lastDrawnMaxLabel[0] = '\0';
  lastDrawnAvgMetricValue = NAN;
  lastDrawnMaxMetricValue = NAN;
}

// Периодическая проверка освещённости с гистерезисом.
void updateAmbientLight(unsigned long nowMs)
{
  if (themeMode != THEME_AUTO)
    return;

  if (nowMs - lastLightRead < LIGHT_UPDATE_MS && lastLightRead != 0)
  {
    return;
  }

  lastLightRead = nowMs;

  int raw = readLightRaw();

  Serial.print("LDR raw: ");
  Serial.println(raw);

  bool shouldBeDark = isDarkTheme;

  if (!isDarkTheme && raw > LIGHT_THRESHOLD_DARK)
  {
    shouldBeDark = true;
  }
  else if (isDarkTheme && raw < LIGHT_THRESHOLD_LIGHT)
  {
    shouldBeDark = false;
  }

  if (shouldBeDark != isDarkTheme)
  {
    isDarkTheme = shouldBeDark;
    applyThemeColors(isDarkTheme);

    if (settingsScreen)
    {
      // На Settings фон не перерисовываем. Меняется только состояние темы.
    }
    else
    {
      drawMainBackground();
      captureMainBackgroundRegions();
        }
    forceFullRedraw();
  }
}


// ============================================================
// СОХРАНЕНИЕ ОДОМЕТРА (без изменений)
// ============================================================

void maybeSaveOdometer()
{
  float distanceSinceSave = odometerKm - odometerAtLastSave;

  if (distanceSinceSave >= ODOMETER_SAVE_STEP_KM)
  {
    prefs.putFloat("odom_km", odometerKm);
    odometerAtLastSave = odometerKm;
  }
}


// ============================================================
// ВЕРХНЯЯ СТРОКА: температура | часы | батарея
// ============================================================
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

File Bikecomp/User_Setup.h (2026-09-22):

//                            USER DEFINED SETTINGS
//   Set driver type, fonts to be loaded, pins used and SPI control method etc.
//
//   See the User_Setup_Select.h file if you wish to be able to define multiple
//   setups and then easily select which setup file is used by the compiler.
//
//   If this file is edited correctly then all the library example sketches should
//   run without the need to make any more changes for a particular hardware setup!
//   Note that some sketches are designed for a particular TFT pixel width/height

// User defined information reported by "Read_User_Setup" test & diagnostics example
#define USER_SETUP_INFO "User_Setup"

// Define to disable all #warnings in library (can be put in User_Setup_Select.h)
//#define DISABLE_ALL_LIBRARY_WARNINGS

// ##################################################################################
//
// Section 1. Call up the right driver file and any options for it
//
// ##################################################################################

// Define STM32 to invoke optimised processor support (only for STM32)
//#define STM32

// Defining the STM32 board allows the library to optimise the performance
// for UNO compatible "MCUfriend" style shields
//#define NUCLEO_64_TFT
//#define NUCLEO_144_TFT

// STM32 8-bit parallel only:
// If STN32 Port A or B pins 0-7 are used for 8-bit parallel data bus bits 0-7
// then this will improve rendering performance by a factor of ~8x
//#define STM_PORTA_DATA_BUS
//#define STM_PORTB_DATA_BUS

// Tell the library to use parallel mode (otherwise SPI is assumed)
//#define TFT_PARALLEL_8_BIT
//#defined TFT_PARALLEL_16_BIT // **** 16-bit parallel ONLY for RP2040 processor ****

// Display type -  only define if RPi display
//#define RPI_DISPLAY_TYPE // 20MHz maximum SPI

// Only define one driver, the other ones must be commented out
//#define ILI9341_DRIVER       // Generic driver for common displays
//#define ILI9341_2_DRIVER     // Alternative ILI9341 driver, see https://github.com/Bodmer/TFT_eSPI/issues/1172
//#define ST7735_DRIVER      // Define additional parameters below for this display
//#define ILI9163_DRIVER     // Define additional parameters below for this display
//#define S6D02A1_DRIVER
//#define RPI_ILI9486_DRIVER // 20MHz maximum SPI
//#define HX8357D_DRIVER
//#define ILI9481_DRIVER
//#define ILI9486_DRIVER
//#define ILI9488_DRIVER     // WARNING: Do not connect ILI9488 display SDO to MISO if other devices share the SPI bus (TFT SDO does NOT tristate when CS is high)
#define ST7789_DRIVER      // Full configuration option, define additional parameters below for this display
//#define ST7789_2_DRIVER    // Minimal configuration option, define additional parameters below for this display
//#define R61581_DRIVER
//#define RM68140_DRIVER
//#define ST7796_DRIVER
//#define SSD1351_DRIVER
//#define SSD1963_480_DRIVER
//#define SSD1963_800_DRIVER
//#define SSD1963_800ALT_DRIVER
//#define ILI9225_DRIVER
//#define GC9A01_DRIVER

// Some displays support SPI reads via the MISO pin, other displays have a single
// bi-directional SDA pin and the library will try to read this via the MOSI line.
// To use the SDA line for reading data from the TFT uncomment the following line:

// #define TFT_SDA_READ      // This option is for ESP32 ONLY, tested with ST7789 and GC9A01 display only

// For ST7735, ST7789 and ILI9341 ONLY, define the colour order IF the blue and red are swapped on your display
// Try ONE option at a time to find the correct colour order for your display

//  #define TFT_RGB_ORDER TFT_RGB  // Colour order Red-Green-Blue
  #define TFT_RGB_ORDER TFT_BGR  // Colour order Blue-Green-Red

// For M5Stack ESP32 module with integrated ILI9341 display ONLY, remove // in line below

// #define M5STACK

// For ST7789, ST7735, ILI9163 and GC9A01 ONLY, define the pixel width and height in portrait orientation
 #define TFT_WIDTH  240
// #define TFT_WIDTH  128
// #define TFT_WIDTH  172 // ST7789 172 x 320
// #define TFT_WIDTH  170 // ST7789 170 x 320
// #define TFT_WIDTH  240 // ST7789 240 x 240 and 240 x 320
 #define TFT_HEIGHT 320
// #define TFT_HEIGHT 128
// #define TFT_HEIGHT 240 // ST7789 240 x 240
// #define TFT_HEIGHT 320 // ST7789 240 x 320
// #define TFT_HEIGHT 240 // GC9A01 240 x 240

// For ST7735 ONLY, define the type of display, originally this was based on the
// colour of the tab on the screen protector film but this is not always true, so try
// out the different options below if the screen does not display graphics correctly,
// e.g. colours wrong, mirror images, or stray pixels at the edges.
// Comment out ALL BUT ONE of these options for a ST7735 display driver, save this
// this User_Setup file, then rebuild and upload the sketch to the board again:

// #define ST7735_INITB
// #define ST7735_GREENTAB
// #define ST7735_GREENTAB2
// #define ST7735_GREENTAB3
// #define ST7735_GREENTAB128    // For 128 x 128 display
// #define ST7735_GREENTAB160x80 // For 160 x 80 display (BGR, inverted, 26 offset)
// #define ST7735_ROBOTLCD       // For some RobotLCD Arduino shields (128x160, BGR, https://docs.arduino.cc/retired/getting-started-guides/TFT)
// #define ST7735_REDTAB
// #define ST7735_BLACKTAB
// #define ST7735_REDTAB160x80   // For 160 x 80 display with 24 pixel offset

// If colours are inverted (white shows as black) then uncomment one of the next
// 2 lines try both options, one of the options should correct the inversion.

// #define TFT_INVERSION_ON
 #define TFT_INVERSION_OFF


// ##################################################################################
//
// Section 2. Define the pins that are used to interface with the display here
//
// ##################################################################################

// If a backlight control signal is available then define the TFT_BL pin in Section 2
// below. The backlight will be turned ON when tft.begin() is called, but the library
// needs to know if the LEDs are ON with the pin HIGH or LOW. If the LEDs are to be
// driven with a PWM signal or turned OFF/ON then this must be handled by the user
// sketch. e.g. with digitalWrite(TFT_BL, LOW);

 #define TFT_BL   27            // LED back-light control pin
 #define TFT_BACKLIGHT_ON HIGH  // Level to turn ON back-light (HIGH or LOW)
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
